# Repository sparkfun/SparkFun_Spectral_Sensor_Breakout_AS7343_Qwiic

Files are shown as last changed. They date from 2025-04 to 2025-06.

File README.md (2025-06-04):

SparkFun Spectral Sensor - AS7343 (Qwiic)
=========================================
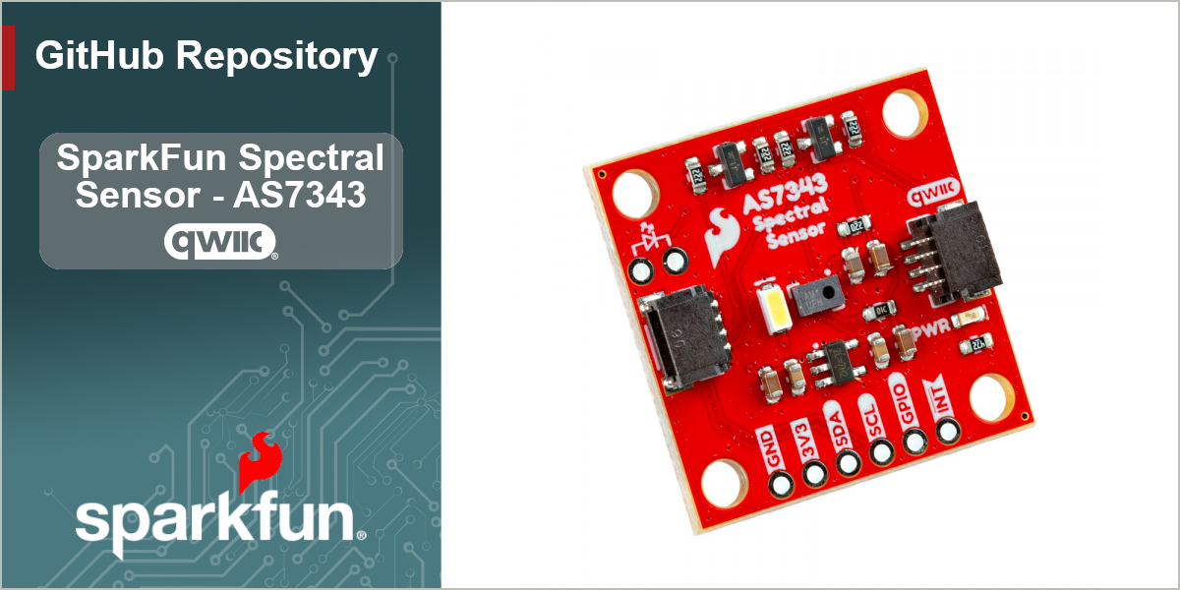
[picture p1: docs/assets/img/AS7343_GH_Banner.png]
Banner image for Spectral Sensor - AS7343 (https://www.sparkfun.com/sparkfun-spectral-sensor-as7343-qwiic.html)
 

The SparkFun Spectral Sensor Breakout - AS7343 (Qwiic) offers a highly accurate but compact spectral analysis tool for both the visible spectrum and near-infrared. The AS7343 senses light between ~380mn to 1000mn over 14 channels with 11 color bands across the visible spectrum, one near-infrared channel, one clear channel (full sensing spectrum) along with flicker detection. The AS7343 also has an interrupt pin to trigger events based on specific measurements from the sensor as well as a programmable GPIO pin to help synchronize measurements with external devices. This breakout comes standard with a bright white LED for taking measurements but also includes connection points for users who wish to use their own LED if needed.

Repository Contents
-------------------

* **/Documentation** - Data sheets, additional product information
* **/Hardware** - Eagle design files (.brd, .sch)
* **/Production** - Production panel files (.brd)
* **/docs** -  Documentation files for the Spectral UV Sensor
* **/overrides** -  Overrides for GitHub pages content

Documentation
--------------
* **[Arduino Library](https://github.com/sparkfun/SparkFun_AS7343_Arduino_Library/tree/main)** - Arduino library for the Spectral Sensor - AS7343 (Qwiic).
* **[Python Package](https://github.com/sparkfun/qwiic_as7343_py)** - Python package for the Spectral Sensor - AS7343 (Qwiic)
* **[Hookup Guide](https://docs.sparkfun.com/SparkFun_Spectral_Sensor_Breakout_AS7343_Qwiic)** - Basic hookup guide for the Spectral Sensor - AS7343 (Qwiic).

Product Versions
----------------
* [SEN-23220](https://www.sparkfun.com/sparkfun-spectral-sensor-as7343-qwiic.html) - Spectral Sensor - AS7343 (Qwiic)

License Information
-------------------

This product is _**open source**_! 

Please review the LICENSE.md file for license information. 

If you have any questions or concerns on licensing, please contact technical support on our [SparkFun forums](https://forum.sparkfun.com/viewforum.php?f=152).

Distributed as-is; no warranty is given.

- Your friends at SparkFun.

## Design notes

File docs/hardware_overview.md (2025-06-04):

Let's take a closer look at the AS7343 and other hardware on the SparkFun Spectral Sensor Breakout - AS7343. The image below highlights the major components on this Qwiic breakout board:

<figure markdown>
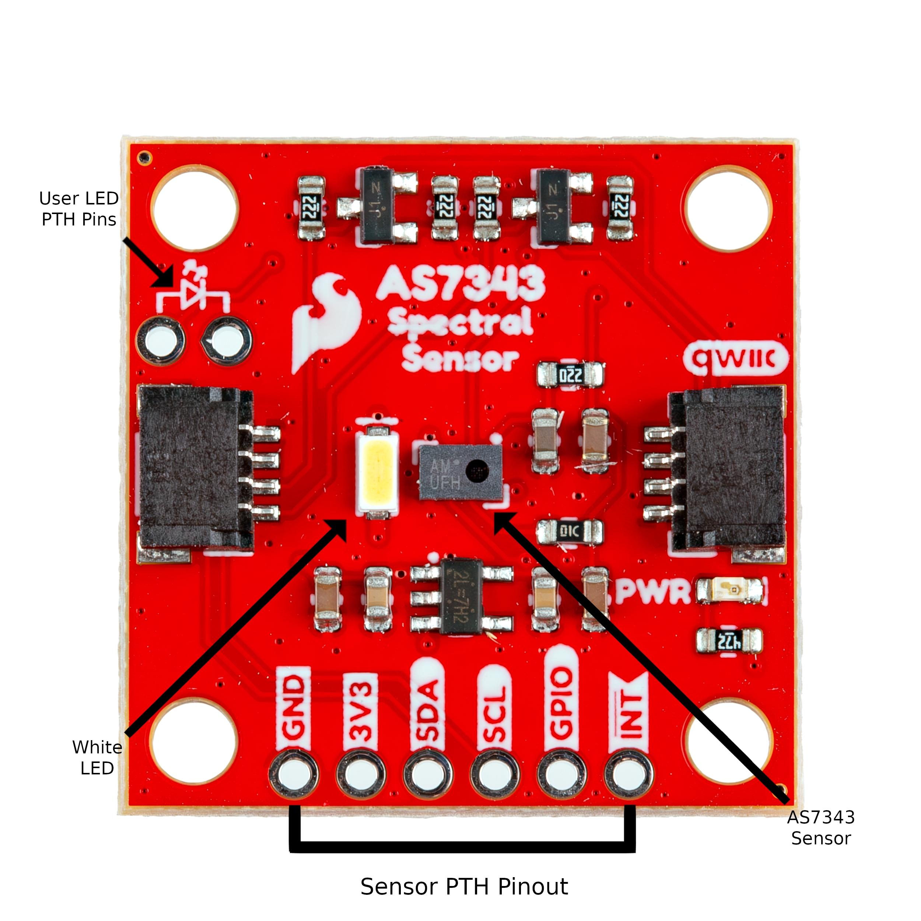
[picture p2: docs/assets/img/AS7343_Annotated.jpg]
Annotated photo of AS7343 Breakout

</figure>

## AS7343 Spectral Sensor

The AS7343 from AMS<sup>&trade;</sup> measures irradiated, reflected and transmitted light in both the visible spectrum and near-infrared (NIR). The sensor features 14 channels in a 5x5 photodiode array, enabling the detection of 11 specific color bands across the visible spectrum. Additionally, dedicated photodiodes on the outer edges of this array are designed for near-infrared (845-865 nm) and flicker detection. It has exceptional sensitivity for measuring reflected, emitted and transmitted light even in low-light environments and also behind tinted glass. 

## Power

Power for the board can be supplied either over one of the Qwiic connectors or through the <b>3.3V</b> pin. The AS7343 accepts a supply voltage between <b>1.7V</b> and <b>2V</b> so the breakout includes an on board voltage regulator to drop the <b>3.3V</b> supplied over Qwiic or <b>3.3V</b> pin to <b>1.8V</b>. This regulator has a max input voltage of <b>5.5V</b>.

## Qwiic & Pinout

The AS7343 communicates over I<sup>2</sup>C and has an active low/high interrupt pin as well as a GPIO pin. The breakout routes the SDA/SCL lines from the AS7343 to a pair of Qwiic connectors as well as the 0.1"-spaced PTH header on the side of the board. The AS7343's interrupt and GPIO are also routed to this PTH.

## LEDs

The Spectral Sensor Breakout - AS7343 has two LEDs on the board labeled <b>PWR</b> and <b>WLED</b>. The red Power (PWR) LED indicates when the board is powered. The white (WLED) LED connects to the AS7343's LED current sink pin to illuminate objects/areas during sensor readings. Users can disable the on board white LED by opening the corresponding solder jumper and connect their own LED to the PTH pins labeled .

## Solder Jumpers

The board has three solder jumpers labeled <b>I2C</b>, <b>PWR</b> and <b>WLED</b>. The <b>I2C</b> jumper is a three-way jumper that pulls the SDA/SCL lines to <b>3.3V</b> through a pair of <b>2.2k&ohm;</b> resistors and is CLOSED by default. The board also includes level shifting to drop the logic down to <b>1.8V</b> . The <b>PWR</b> jumper completes the power LED circuit and is CLOSED by default. Open the solder jumper to disable the power LED. The <b>WLED</b> jumper completes the white LED circuit and is CLOSED by default.

## Board Dimensions

The SparkFun Spectral Sensor Breakout - AS7343 matches the Qwiic breakout standard and measures 1" x 1" (22.5mm x 22.5mm) and has four mounting holes that fit a [4-40 screw](https://www.sparkfun.com/screw-phillips-head-1-4-4-40-10-pack.html).

<figure markdown>
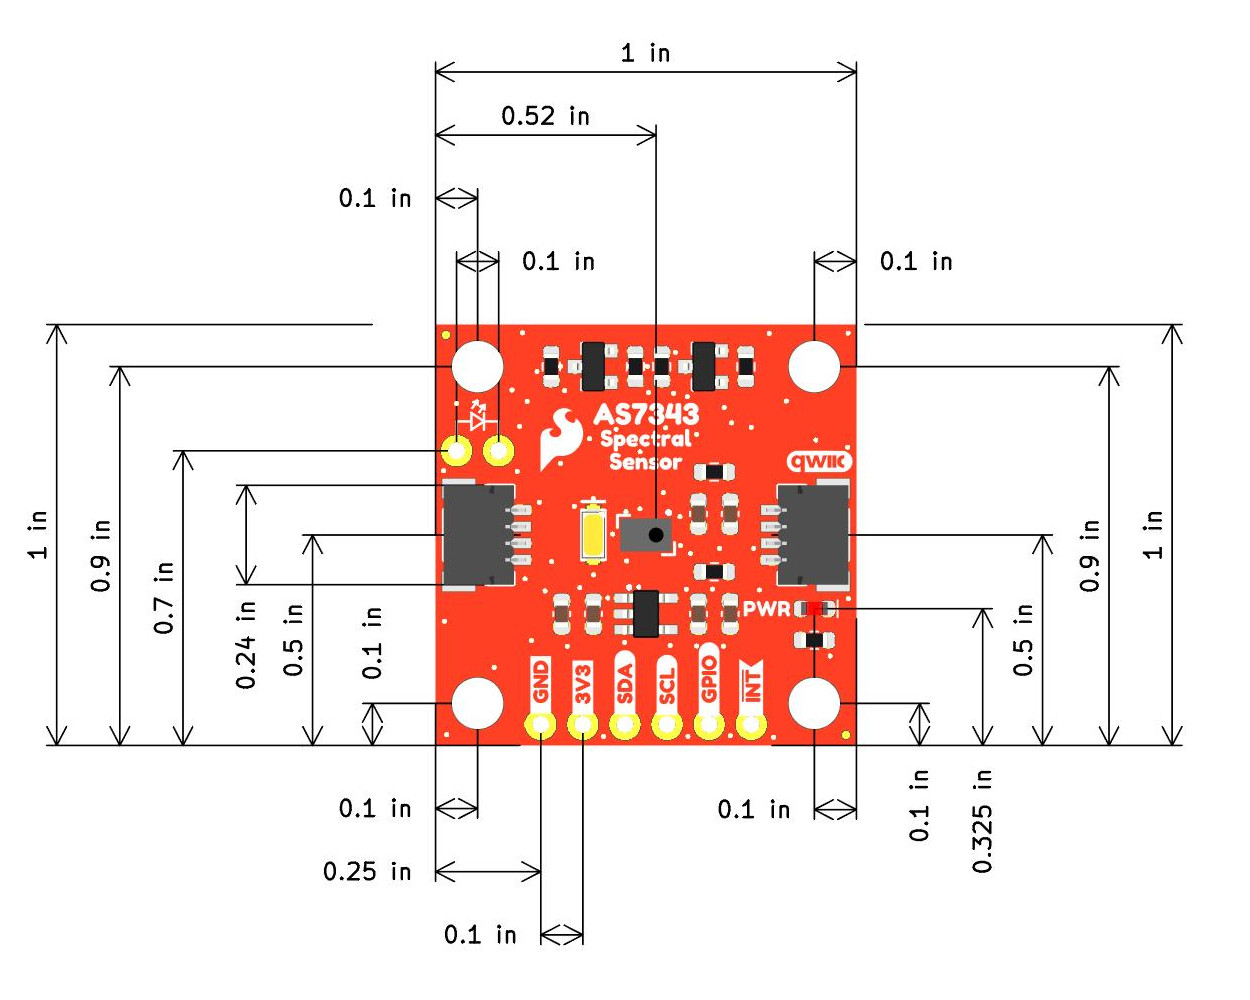
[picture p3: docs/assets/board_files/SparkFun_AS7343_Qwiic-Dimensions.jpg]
Dimensional drawing

</figure>

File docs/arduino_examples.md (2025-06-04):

Let's take a closer look at the examples included in the SparkFun AS7343 Arduino Library. This section assumes users are following the assembly instructions from the Hardware Assembly/Qwiic Start sections and are using a SparkFun RedBoard IoT - ESP32.

## Example 1 - Basic Readings

The first example sets up the AS7343 to operate with default settings and outputs data from just four channels (Red, Green, Blue and NIR). Open the example in Arduino by navigating to **File** > **Examples** > **SparkFun AS7343 Arduino Library** > **Example_01_BasicReadings**. Next, select your board (RedBoard IoT - ESP32) and Port and click the "Upload" button. After the code finishes compiling and uploading, open the [serial monitor](https://docs.arduino.cc/software/ide-v2/tutorials/ide-v2-serial-monitor/) with the baud set to **115200** and you should see readings for red, blue, green and NIR print out like the screenshot below shows:

<figure markdown>
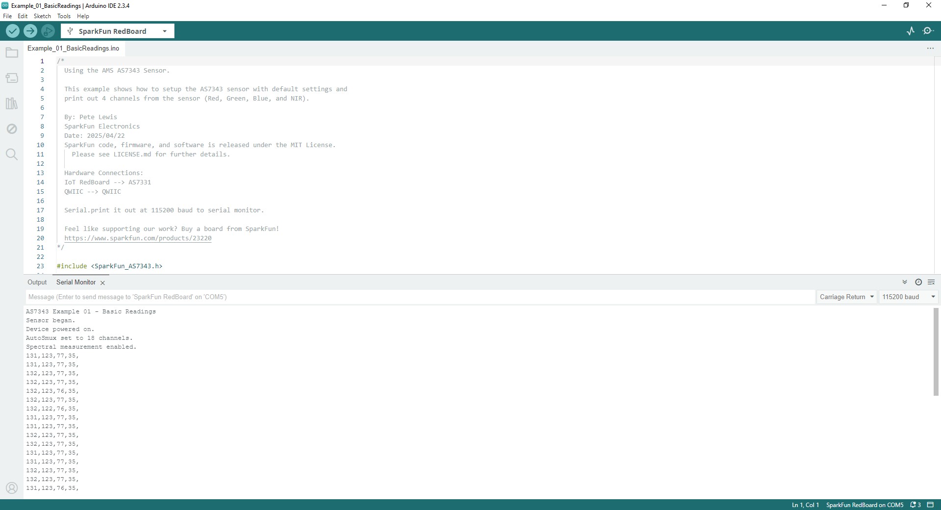
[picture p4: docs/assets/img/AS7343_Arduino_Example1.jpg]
Screenshot of example 1 serial print

</figure>

## Example 2 - All Channels

Example 2 - All Channels shows how to set up the AS7343 with default settings to print out all spectral data from the sensor. This example is nearly identical to the first outside of the serial data printed out. Instead of getting and printing data from four specific channels, this example requests data from all channels and prints it as comma separated values. Open the example in Arduino by navigating to **File** > **Examples** > **SparkFun AS7343 Arduino Library** > **Example_02_AllChannels**. 

In order to get data from all channels, the AS7343 takes measurements in three cycles with each one stepping through four individual channels combined with readings from the Clear/VIS and Flicker Detect/FD which is then stored in the sensor's data registers. The example prints out spectral data stepping through each channel from 0 to 17 in comma-separated values:

```c++
    for (int channel = 0; channel < channelsRead; channel++)
    {
        Serial.print(myData[channel]);
        Serial.print(",");
    }

    Serial.println();
```

## Example 3 - Gain

The third example shows how to set up the AS7343 with specific Spectral Engines Gain Settigns (aka AGAIN) and cycle through the gain settings using serial commands. Open the example in Arduino by navigating to **File** > **Examples** > **SparkFun AS7343 Arduino Library** > **Example_03_Gain**. If necessary, select your board and port and click the "Upload" button. Open the serial terminal with the baud set to **115200** after the code finishes uploading. 

The example accepts serial inputs of "+" and "-" to step up and down, respectively, through the available gain settings and prints out the value of the gain each time it's updated:

```c++
    if(Serial.available())
    {
        userInput = Serial.read();
        if (userInput == '+' || userInput == '-')
        {
            updateGainSetting(userInput);
        }
    }
```

The code also prints out spectral readings from all channels every 1 second so'll want to pay close attention to the serial monitor when adjusting the gain value to see the returned serial data like the screenshot below shows:

<figure markdown>
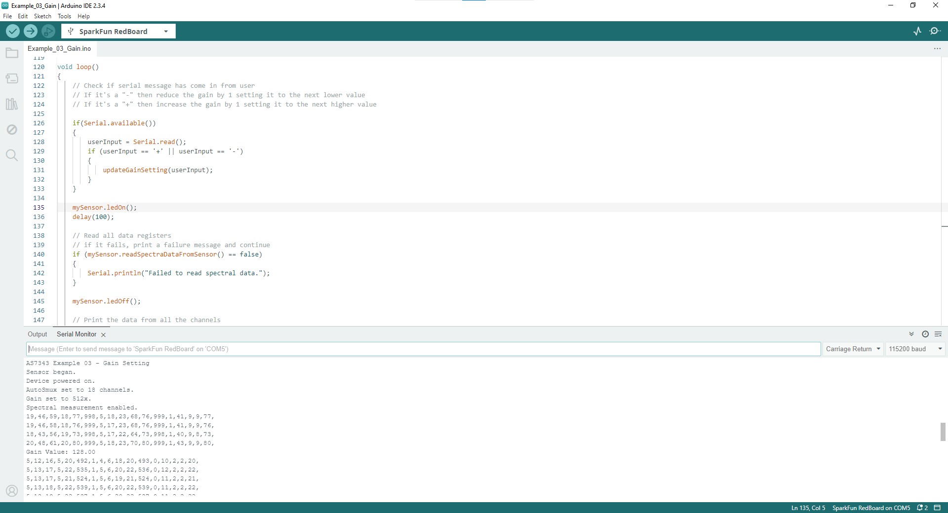
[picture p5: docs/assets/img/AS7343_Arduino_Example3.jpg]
Screenshot of Example 3 - Gain serial printout.

</figure>

## Example 4 - Interrupt

The fourth example demonstrates how to set up the AS7343's interrupt pin to fire when values from a specific channel exceed a specified limit. The example defaults to watch channel FZ (450nm aka Blue) and trigger the interrupt when it reports values over 10 counts. The example defaults to use `D4` for the interrupt pin so depending on whether or not your board supports external interrupts adjust this line if needed:

```c++
#define INT_HW_READ_PIN 4 // Pin to read the interrupt pin from the AS7343
```

Not sure which pins on your development board support the `attachInterrupt()` function in Arduino? Take a look at [this page](https://docs.arduino.cc/language-reference/en/functions/external-interrupts/attachInterrupt/) for a more thorough reference on the function along with available interrupt pins for common Arduino development boards.

## Example 5 - Flicker Detection

Example five shows how to set up and monitor flicker detection readings from the sensor. It sets up the AS7343 with default settings with flicker detection enabled. It then checks to see if flicker detection values are invalid or saturated and prints out for either case:

**Flicker Detection is Invalid**
```c++
if (fdValid == false)
    {
        Serial.print("Flicker Detection Measurement Invalid");
        Serial.println();
        delay(1000);
        return;
    }
```
**Flicker Detection Saturated**
```c++
    if (fdSaturation == true)
    {
        Serial.print("Flicker Detection Saturation Detected");
        Serial.println();
        delay(1000);
        return;
    }
```

If the flicker detection value is valid and not saturated, it reads the value and prints it in Hz over serial:

```c++
    if(fdValid == true && fdSaturation == false)
    {
        if (fdFrequency == 0) // if getFlickerDetectionFrequency() returns 0, no frequency detected
            Serial.print("No Flicker Detected");
        else
        {
            Serial.print("Flicker Detected at frequency: ");
            Serial.print(fdFrequency);
            Serial.print("Hz");
        }
        Serial.println();
    }

    delay(1000);
```

## Example 6 - Sleep

Example six shows how to put the AS734 in and out of "sleep" to take intermittent measurements. Note, the AS7343 [datasheet](./assets/component_documentation/AS7343_DS001046_6-00.pdf) refers to each mode of operation as Sleep, Idle and Active. There is no direct control of a power mode but we can turn off the Measurement and the Power ON bits in the Enable register to put the AS7343 into a low power state that draws ~350uA. This example creates helper functions to wake the sensor, take a reading and then put the sensor back to sleep once every five seconds in the main loop:

```c++
void loop()
{
    takeReading(); // Wake up and take a reading from the sensor

    sleepSensor(); // Disables measurement (IDLE) and powers off (SLEEP)

    delay(5000); // Wait 5 seconds to allow reading sleep current if needed.
}
```

## Example 7 - Web Terminal Bar Graph

The seventh example takes data from all of the AS7343's channels (visible spectrum, NIR and clear) and formats it in a way to work with the SparkFun [Web Serial Plotter](https://docs.sparkfun.com/SparkFun_WebSerialPlotter/) tool to display the readings in a colorful bar graph. After uploading the code, open the [SparkFun Web Serial Plotter](https://docs.sparkfun.com/SparkFun_WebSerialPlotter/) site, select the COM port with the baud set to <b>115200</b> and click connect. You should start to see serial data print out in the top window along with a bar graph matching the channel data in the bottom window:

<figure markdown>
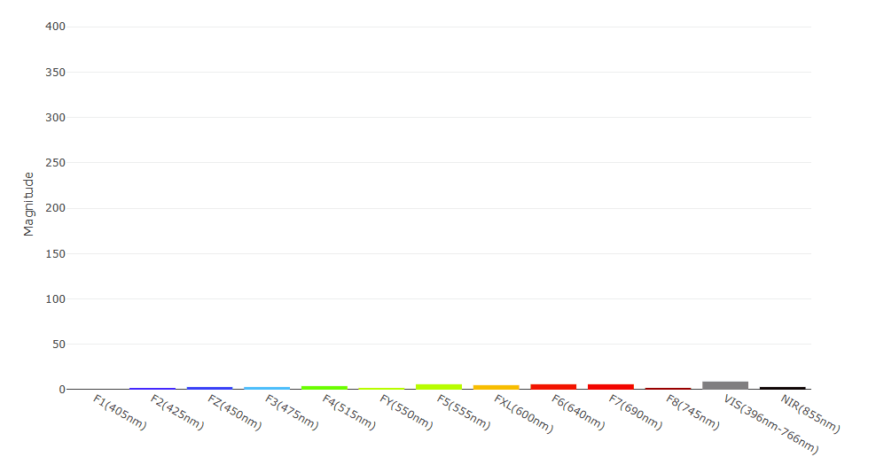
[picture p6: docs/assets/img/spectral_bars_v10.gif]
Gif of bar graph demo

</figure>

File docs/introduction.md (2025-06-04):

<figure markdown>
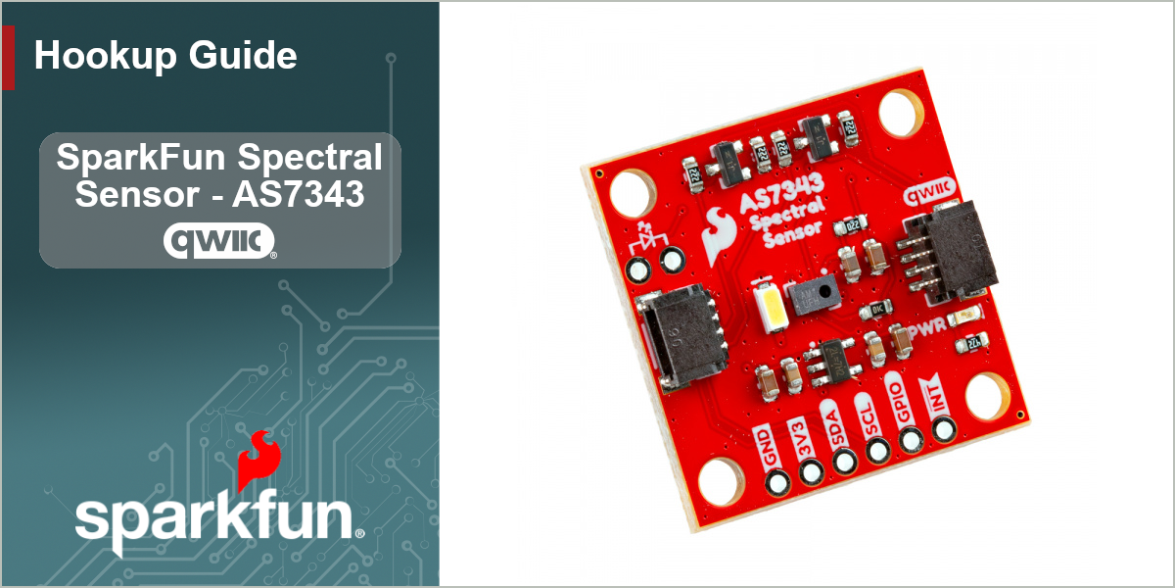
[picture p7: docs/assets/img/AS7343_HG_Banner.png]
Spectral Sensor Breakout Banner Image

</figure>

The SparkFun Spectral Sensor Breakout - AS7343 (Qwiic) offers a highly accurate but compact spectral analysis tool for both the visible spectrum and near-infrared. The AS7343 senses light between ~380mn to 1000mn over 14 channels with 11 color bands across the visible spectrum, one near-infrared channel, one clear channel (full sensing spectrum) along with flicker detection. The AS7343 also has an interrupt pin to trigger events based on specific measurements from the sensor as well as a programmable GPIO pin to help synchronize measurements with external devices. This breakout comes standard with a bright white LED for taking measurements but also includes connection points for users who wish to use their own LED if needed.

This guide covers how to get spectral data from the AS7343 using both Arduino and MicroPython when connecting the Spectral Sensor Breakout to a compatible development board over Qwiic. In order to follow along with this guide you'll need the Spectral Sensor Breakout - AS7343 along with the following materials:

* [SparkFun IoT RedBoard - ESP32 MicroPython Development Board](https://www.sparkfun.com/sparkfun-iot-redboard-esp32-micropython-development-board.html) (or other Arduino/MicroPython development board)
* [Qwiic Cable](https://www.sparkfun.com/qwiic-cable-100mm.html)
* [USB-C Cable](https://www.sparkfun.com/usb-a-to-usb-c-cable-1m-usb-2-0-flexible-silicone.html) 

If you plan to use the AS7343's Interrupt/GPIO pins or prefer a soldered connection, you may need one or more of these materials along with a [soldering iron](https://www.sparkfun.com/tools/soldering/soldering-irons-and-tips.html) and [solder](https://www.sparkfun.com/tools/soldering/solder.html):

* [Breakaway Headers Straight](https://www.sparkfun.com/break-away-headers-straight.html)
* [Jumper Wires - Connected 6" (M/M, 20 pack)](https://www.sparkfun.com/jumper-wires-connected-6-m-m-20-pack.html)
* [Breadboard](https://www.sparkfun.com/breadboard-self-adhesive-white.html)

## Topics Covered

This document contains three main sections: **Quickstart Guide**, **Hardware** and **Software**. 

The Quickstart Guide assumes a working knowledge of how to use a development board and the required software to program them for your project's needs. It covers a quick assembly and then jumps right into getting the necessary software packages installed to start getting spectral data in just a few short minutes.

The Hardware pages are split into the Hardware Overview and Hardware Assembly. The Hardware Overview provides a detailed overview of the Spectral Sensor Breakout - AS7343 along with all the major components included on the board. Refer to this page for information on things like the AS7343, LEDs, pinout and solder jumpers. The Hardware Assembly page covers how to assemble the breakout in both a Qwiic circuit as well as how to use the optional soldered features such as the external LED and the AS7343's Interrupt/GPIO pins.

The Software pages are split into sections covering the SparkFun AS7343 Arduino Library and MicroPython driver. Each software page gives instructions on how to download install the software package (Arduino library or MicroPython driver), as well as detailed looks at the examples included in the software packages.

## Resources and Support Documentation 

You'll find the board design files (KiCad files & schematic), relevant documentation (datasheets, white papers, etc.) and other helpful links in the **Resources**. Lastly, the **Support** section includes a Troubleshooting page that includes any helpful tips specific to this board as well as information on how to receive technical support from SparkFun.

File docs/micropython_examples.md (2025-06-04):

Let's take a quick look at each example included in the SparkFun AS7343 Python package. Note, the naming of these examples matches the examples in the Arduino library and skips from 3 to 5 as this package does not have an interrupt example (Example 4 in the Arduino library).

## Example 1 - Basic Readings

This simple example demonstrates how to set up the AS7343 with default settings and though it does set the AS7343 to report data from all 18 channels it only prints data for four channels (Red, Green, Blue and NIR) using this command:

```py
	print(myAS7343.get_blue(), end=',')
		print(myAS7343.get_red(), end=',')
		print(myAS7343.get_green(), end=',')
		print(myAS7343.get_nir(), end=',\n')
```

## Example 2 - All Channels

Example 2 demonstrates how to set up the AS7343 to output data from all channels on the sensor in comma-separated values by steping through all channels:

```py
	for i in range(0, myAS7343.kNumChannels):
			print(myAS7343.get_data(i), end=',')
		print()
```

## Example 3 - Gain

The third example shows how to set the gain for the AS7343. It defaults to set the gain as `512x` but you can adjust it in this line:

```py
if not myAS7343.set_a_gain(myAS7343.kAgain64):
```

Refer to the main .py file [here](https://github.com/sparkfun/qwiic_as7343_py/blob/master/qwiic_as7343.py#L102) for all allowed values for gain settings.

## Example 5 - Flicker Detection

The Flicker Detection example demonstrates how to use the AS7343's flicker detection feature. It initializes the sensor with default settings and then prints out flicker detection vlues in Hz to the serial monitor:

```py
if fdFrequency == 0:
			print("No flicker detected")
		else:
			print("Flicker detected at frequency: {} Hz".format(fdFrequency))

		time.sleep(1)
```

## Example 6 - Sleep

The sixth example shows how to create a `def` to cycle the AS7343 in and out of "sleep" between measurement reports to help conserve power:

```py
def sleep_device(device):
	# Disable spectral measurements
	if not device.spectral_measurement_disable():
		print("Failed to disable spectral measurements", file=sys.stderr)
		return
	print("Spectral measurements disabled")

	# Power off the device
	if not device.power_off():
		print("Failed to power off the device", file=sys.stderr)
		return
	print("Device powered off")
```

The main example then initializes the sensor with default settings, takes readings, puts it to sleep for 5 seconds and then loops:

```py
	while True:
		# Take a reading
		take_reading(myAS7343)

		# Put the device to sleep
		sleep_device(myAS7343)

		# Wait 5 seconds before taking another reading
		time.sleep(5.0)
```

Though there is no direct control of a power mode, the example turns off the measurement and Power ON bits in the Enable register to put the sensor into a low power state so it draws ~350&micro;A.

## Example 7 - Web Bar Graph

Example 7 shows how to use the Spectral Sensor with the SparkFun [Web Serial Plotter](https://docs.sparkfun.com/SparkFun_WebSerialPlotter/) to display spectral data from all channels in a neat and colorful bar graph. You'll need to run this on a microcontroller like the [IoT RedBoard - ESP32 MicroPython](https://www.sparkfun.com/sparkfun-iot-redboard-esp32-micropython-development-board.html) as the Web Serial Plotter connects over a serial COM port. The code initializes the AS7343 with default settings and then prints out the comma-separated values in a format compatible with the web serial plotter:

```py
print(f"{myAS7343.get_data(myAS7343.kChPurpleF1405nm)},"
          f"{myAS7343.get_data(myAS7343.kChDarkBlueF2425nm)},"
          f"{myAS7343.get_data(myAS7343.kChBlueFz450nm)},"
		  f"{myAS7343.get_data(myAS7343.kChLightBlueF3475nm)},"
		  f"{myAS7343.get_data(myAS7343.kChBlueF4515nm)},"
		  f"{myAS7343.get_data(myAS7343.kChGreenF5550nm)},"
		  f"{myAS7343.get_data(myAS7343.kChGreenFy555nm)},"
		  f"{myAS7343.get_data(myAS7343.kChOrangeFxl600nm)},"
		  f"{myAS7343.get_data(myAS7343.kChBrownF6640nm)},"
		  f"{myAS7343.get_data(myAS7343.kChRedF7690nm)},"
		  f"{myAS7343.get_data(myAS7343.kChDarkRedF8745nm)},"
		  f"{myAS7343.get_data(myAS7343.kChVis1)},"
		  f"{myAS7343.get_data(myAS7343.kChNir855nm)}\n", end='')
```

After running the example, open the [Web Serial Plotter](https://docs.sparkfun.com/SparkFun_WebSerialPlotter/) and select the COM port and click "Connect" and you should see serial data print out in the top window and a nice colorful bar graph in the bottom window like the gif below shows:

<figure markdown>
Gif of serial plotter bar graph spectral data
</figure>

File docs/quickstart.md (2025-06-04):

In this Quick Start Guide we'll connect the SparkFun Spectral Sensor Breaout - AS7343 (Qwiic) to an IoT RedBoard - ESP32 to output measurements of visible and near-infrared light and display them in a colorful web terminal bar graph.

If you're not familiar with using sensor breakouts, development boards or the development environments covered in this guide, refer to the [Hardware](./hardware_overview.md) & [Arduino Setup](./arduino_setup.md) sections of this Hookup Guide for a detailed overview of the board along with instructions on setting up and using the SparkFun AS7343 Arduino Library. For those who prefer to run this example in MicroPython, read on to the [AS7343 Python Setup](./micropython_setup.md) and [Python Examples](./micropython_examples.md) sections of this guide.

## Basic Assembly

As this is a Qwiic breakout, assembling the circuit only requires connecting the sensor breakout to a Qwiic-compatible development board like the IoT RedBoard - ESP32. Connect the Spectral Sensor Breakout to the IoT RedBoard with a Qwiic cable and then connect the IoT RedBoard to your computer with a USB-C cable like the photo below demonstrates:

<figure markdown>
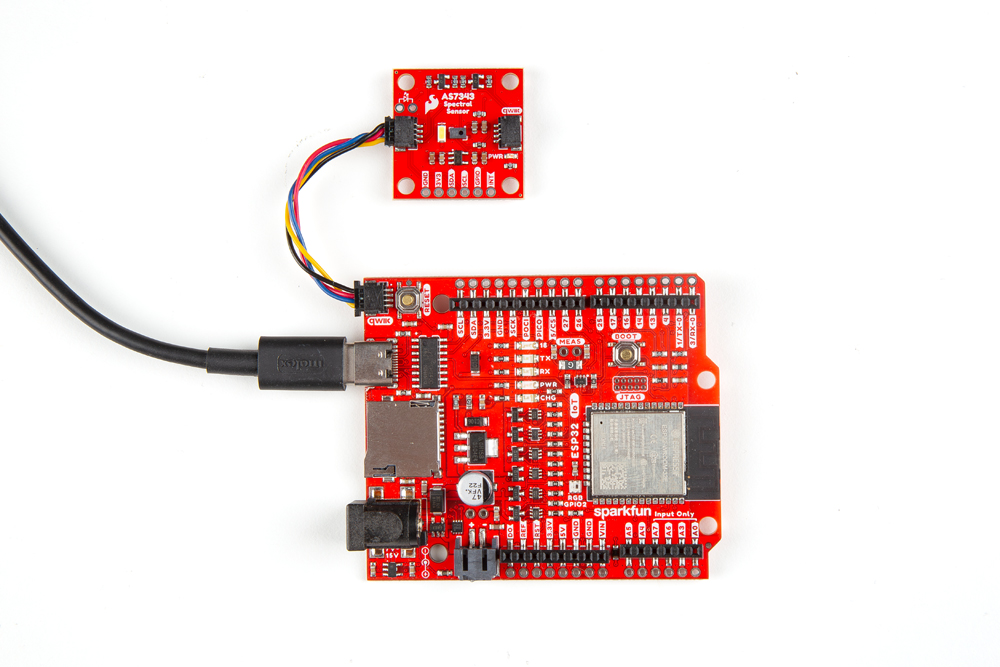
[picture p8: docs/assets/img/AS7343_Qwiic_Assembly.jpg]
Photo of Qwiic assembly with RedBoard IoT - ESP32

</figure>

## Arduino Web Terminal Bar Graph Example

The Arduino Web Terminal Bar Graph example sets up the AS7343 to output from all channels and format the data to work with the [SparkFun Web Serial Plotter](https://docs.sparkfun.com/SparkFun_WebSerialPlotter/) tool and display it in a bar graph. The Web Terminal Bar Graph site only works in a Chromium-based browser (sorry, no Firefox) and just requires a serial connection over USB to your microcontroller.

* Open the [Arduino IDE](https://docs.arduino.cc/software/ide-v2/tutorials/getting-started-ide-v2/)
* Open the [Library Manager](https://docs.arduino.cc/software/ide-v1/tutorials/installing-libraries/) tool and search for "SparkFun Toolkit" and "SparkFun AS7343" and install the latest versions of both libraries.
* If necessary, open the [Boards Manager](https://docs.arduino.cc/software/ide-v2/tutorials/ide-v2-board-manager/) and search for "ESP32" to install the IoT RedBoard - ESP32 board definition.
* Open "Example 7 - Web Terminal Bar Graphs" from the SparkFun AS7343 Arduino Library and select your board (IoT RedBoard - ESP32) and Port.
* Click the "Upload" button and wait for the code to finish compiling and uploading.
* Open [this link](https://docs.sparkfun.com/SparkFun_WebSerialPlotter/) in a browser and select the COM port of the IoT RedBoard.
* Try moving the Spectral Sensor around and pointing it at different objects/colors and watch the Bar Graph in the bottom half of the window update every 1s like the gif below.

<figure markdown>
Screencapture of bar graph in motion
</figure>

**Code to Note**

The code begins by setting the AS7343 to operate with default settings and prints out whether or not it fails or begins:

```c++
    if (mySensor.begin() == false)
    {
        Serial.println("Sensor failed to begin. Please check your wiring!");
        Serial.println("Halting...");
        while (1)
            ;
    }

    Serial.println("Sensor began.")
```

After initializing the sensor and powering it on, the code then sets the AS7343's AutoSmux to output all 18 channels and prints out the result:

```c++
    if (mySensor.setAutoSmux(AUTOSMUX_18_CHANNELS) == false)
    {
        Serial.println("Failed to set AutoSmux.");
        Serial.println("Halting...");
        while (1)
            ;
    }
    Serial.println("AutoSmux set to 18 channels.");
```

The main loop turns the white LED on to illuminate the sensing area and then takes a reading from all channels once per second:

```c++
    mySensor.ledOn();
    delay(100);

    // Read all data registers
    // if it fails, print a failure message and continue
    if (mySensor.readSpectraDataFromSensor() == false)
    {
        Serial.println("Failed to read spectral data.");
    }
```

Finally, in order to format the data for the web serial terminal, the code fills the buffer with channel data in a specific order and prints the buffer for the web terminal to output the bar graph data correctly:

```c++
    sprintf(buffer, "%d,%d,%d,%d,%d,%d,%d,%d,%d,%d,%d,%d,%d\n",
           mySensor.getChannelData(CH_PURPLE_F1_405NM),
           mySensor.getChannelData(CH_DARK_BLUE_F2_425NM),
           mySensor.getChannelData(CH_BLUE_FZ_450NM),
           mySensor.getChannelData(CH_LIGHT_BLUE_F3_475NM),
           mySensor.getChannelData(CH_BLUE_F4_515NM),
           mySensor.getChannelData(CH_GREEN_F5_550NM),
           mySensor.getChannelData(CH_GREEN_FY_555NM),
           mySensor.getChannelData(CH_ORANGE_FXL_600NM),
           mySensor.getChannelData(CH_BROWN_F6_640NM),
           mySensor.getChannelData(CH_RED_F7_690NM),
           mySensor.getChannelData(CH_DARK_RED_F8_745NM),
           mySensor.getChannelData(CH_VIS_1),
           mySensor.getChannelData(CH_NIR_855NM));

    Serial.print(buffer);
```

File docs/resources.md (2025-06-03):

Refer to the resources below for more information on the SparkFun Spectral Sensor Breakout - AS7343 (Qwiic)

* [Schematic](./assets/board_files/SparkFun_AS7343_Qwiic.pdf)
* [KiCad Files](./assets/board_files/SparkFun_AS7343_Qwiic.zip)
* [Board Dimensions](./assets/board_files/SparkFun_AS7343_Qwiic-Dimensions.jpg)
* [Datasheet](./assets/component_documentation/AS7343_DS001046_6-00.pdf) (AS7343)
* [SparkFun AS7343 Arduino Library](https://github.com/sparkfun/SparkFun_AS7343_Arduino_Library)
* [SparkFun AS7343 Python Package](https://github.com/sparkfun/qwiic_as7343_py)
* [GitHub Repository](https://github.com/sparkfun/SparkFun_Spectral_Sensor_Breakout_AS7343_Qwiic)

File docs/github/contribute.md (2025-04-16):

# Contribute: Make an Augmentation!
Spot an improvement opportunity? Feel free to contribute to our open-source design and documentation. 

## :material-file-document-multiple:&nbsp;Improve our Documentation
All of this documentation can be modified by you! Please help us make it better.

* These pages are contained in the [`docs` folder](https://github.com/sparkfun/SparkFun_Spectral_Sensor_Breakout_AS7343_Qwiic/tree/main/docs) of the [SparkFun Spectral Sensor Breakout - AS7343 (Qwiic) repository](https://github.com/sparkfun/SparkFun_Spectral_Sensor_Breakout_AS7343_Qwiic).

<!-- ### :material-source-pull:&nbsp;Submit a Correction -->
### Submit a Correction

1. With a GitHub account, [fork this repository](https://github.com/sparkfun/SparkFun_Spectral_Sensor_Breakout_AS7343_Qwiic/fork).
2. Add your corrections or improvements to the markdown file.
3. File a pull request with your changes, and enjoy making the ~~words~~ ~~worlds~~ world a better place.
	* Once received, the documentation specialist will automatically be notified.
	* We will review your suggested improvements to make sure they are correct and fit within our documentation standards.

## :material-cog:&nbsp;Improve our Hardware Design
All of our designs are open-source! Please help us make it better.

* Our board design files are contained in the [`Hardware` folder](https://github.com/sparkfun/SparkFun_Spectral_Sensor_Breakout_AS7343_Qwiic/tree/main/Hardware) of the [Spectral_Sensor_Breakout_AS7343_Qwiic repository](https://github.com/sparkfun/SparkFun_Spectral_Sensor_Breakout_AS7343_Qwiic).

<!-- ### :material-source-pull:&nbsp;Submit a Design Enhancement -->
### Submit a Design Enhancement

1. With a GitHub account, [fork this repository](https://github.com/sparkfun/SparkFun_Spectral_Sensor_Breakout_AS7343_Qwiic/fork).
2. Add your design augmentation(s)
3. File a pull request with your changes, and enjoy making the ~~words~~ ~~worlds~~ world a better place.
	1. Once received, the engineer in charge of the original design will automatically be notified.
	2. We will review your suggested improvement(s) to verify that they are within our board design standards and meet our product design requirements.
	3. If approved, we will flag these changes for our next board revision. Congrats! 🍻

		!!! info
			Even if your suggestion is accepted, these changes may not be immediately available for purchase. We may have to cycle through our current product inventory first.

## Contributors&nbsp;:clap:
Let's provide some recognition to the contributors for this project!

GitHub Contributors Image
<br>


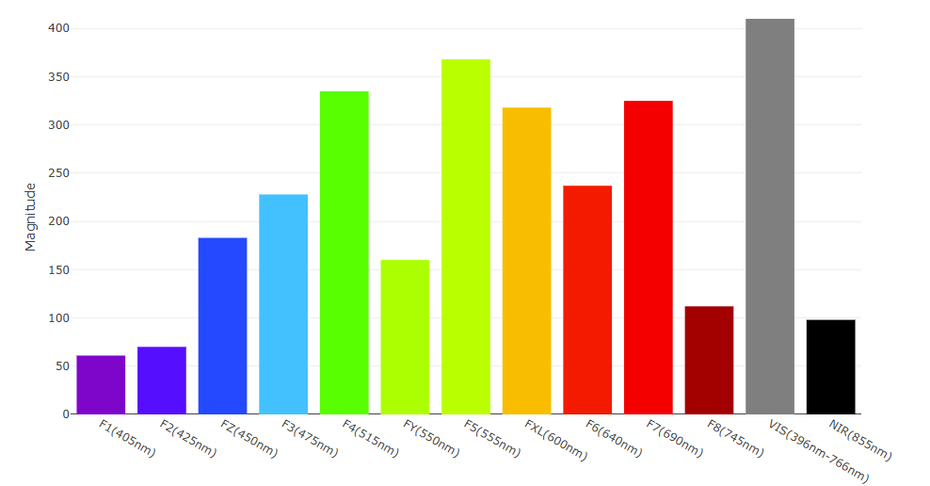
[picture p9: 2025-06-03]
docs/assets/img/spectral_sensor_bars_image.png

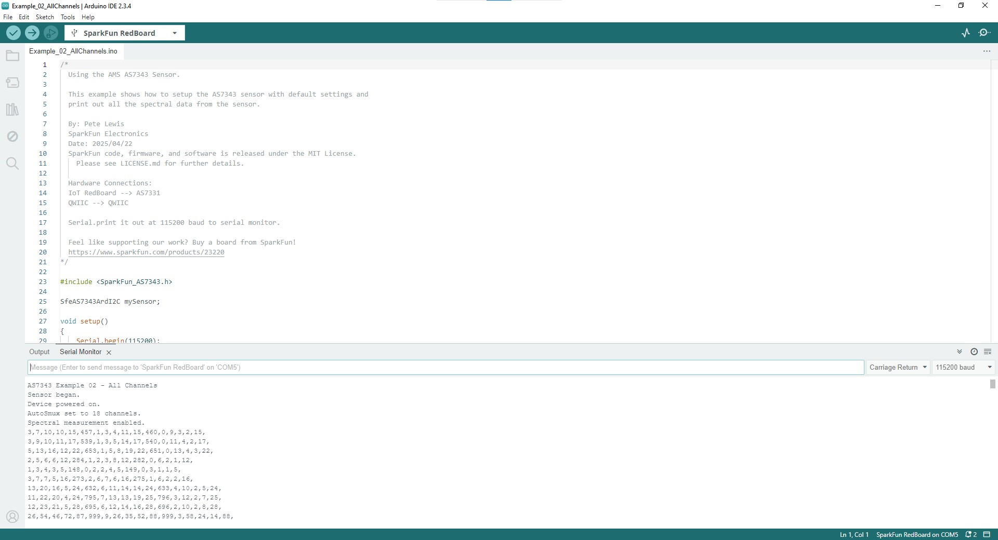
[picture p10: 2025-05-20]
docs/assets/img/AS7343_Arduino_Example2.jpg

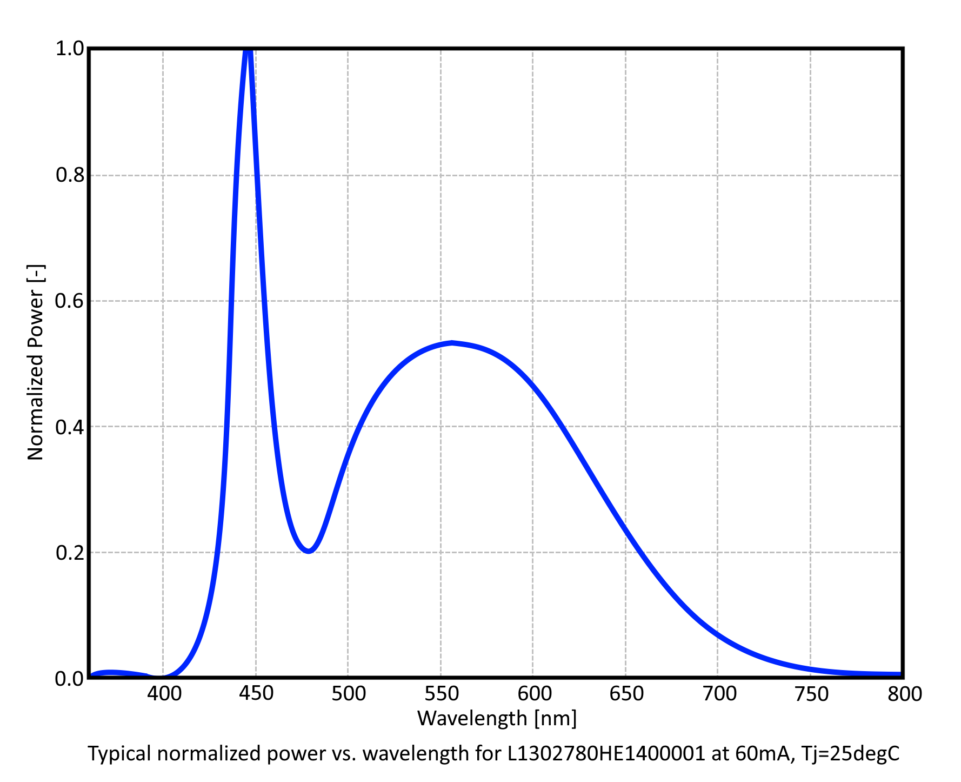
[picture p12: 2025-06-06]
Documents/LUXEON_LED_power_graph.png

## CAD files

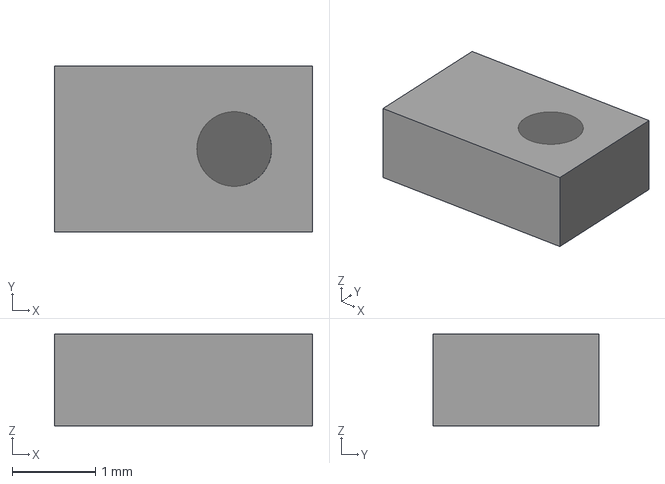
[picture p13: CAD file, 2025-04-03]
Hardware/3D_Models/AS7343_OLGA8.step
3.10 x 2.00 x 1.10 mm

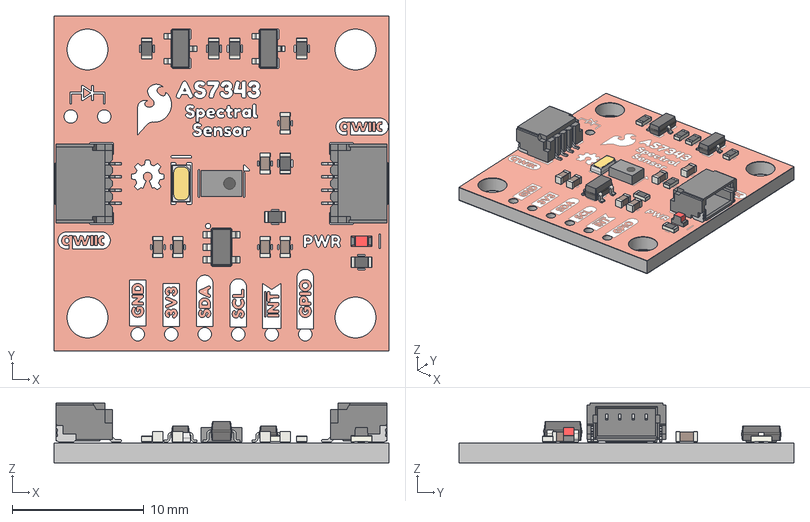
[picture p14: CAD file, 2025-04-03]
Hardware/SparkFun_AS7343_Qwiic.step
25.4 x 25.4 x 4.63 mm
C_0603_1608Metric x 6
R_0603_1608Metric x 7
LUXEON_3014
LED_0603_1608Metric_Red
SOT-23-5
Qwiic-Horizontal x 2
AS7343_OLGA8
SOT-23 x 2
SparkFun_AS7343_Qwiic_silkscreen
SparkFun_AS7343_Qwiic_soldermask
SparkFun_AS7343_Qwiic_PCB

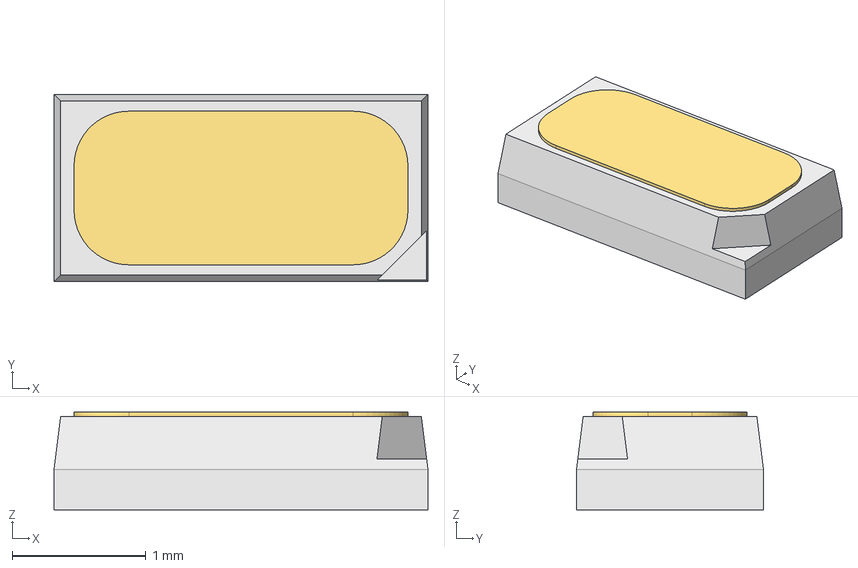
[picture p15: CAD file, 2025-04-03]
Hardware/3D_Models/LUXEON_3014.step
2.80 x 1.40 x 0.73 mm

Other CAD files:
Hardware/3D_Models/AS7343_OLGA8.FCStd
Hardware/3D_Models/LUXEON_3014.FCStd

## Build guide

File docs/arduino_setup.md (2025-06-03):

!!! arduino
    This example assumes you are using the latest version of the Arduino IDE on your desktop. If this is your first time using Arduino IDE, library, or board add-on, please readh through the following tutorials:

    - [Installing the Arduino IDE](https://learn.sparkfun.com/tutorials/installing-arduino-ide)
    - [Installing an Arduino Library](https://learn.sparkfun.com/tutorials/installing-an-arduino-library)
    - [Installing Board Definitions in the Arduino IDE](https://learn.sparkfun.com/tutorials/installing-board-definitions-in-the-arduino-ide)

The SparkFun AS7343 Arduino Library helps users get started with the AS7343 with seven examples that go through how to use different features of the AS7343. The library is built around the [SparkFun Arduino Toolkit](https://github.com/sparkfun/SparkFun_Toolkit) and requires installation of both libraries to work. Install the libraries using the [Arduino library manager](https://docs.arduino.cc/software/ide-v1/tutorials/installing-libraries/) by opening the tool and searching for "SparkFun Toolkit" and "SparkFun AS7343" and installing the latest releases of both libraries. Users who prefer to manually install the libraries can download ZIP files of them here: [SparkFun Toolkit (ZIP)](https://github.com/sparkfun/SparkFun_Toolkit/archive/refs/heads/main.zip) and [SparkFun AS7343 Arduino Library (ZIP)](https://github.com/sparkfun/SparkFun_AS7343_Arduino_Library/archive/refs/heads/main.zip).

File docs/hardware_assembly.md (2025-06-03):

Now that we're familiar with the hardware on this Qwiic breakout, let's build it into a Qwiic circuit to start getting spectral data from the AS7343.

## Qwiic Assembly

The Qwiic system allows solderless connections for power and I<sup>2</sup>C so all you need to get up and running is a Qwiic cable and Qwiic compatible development board (or a Qwiic adapter cable). Assemble your Qwiic circuit by connecting the Spectral Sensor Breakout - AS7343 to your development board with the Qwiic cable and then connecting the development board to your computer over USB like the photo below shows:

<figure markdown>
Photo of Qwiic assembly with RedBoard IoT - ESP32
</figure>

## Using an External LED

If you'd like to install your own LED on the breakout board you'll need to disable the on-board LED and solder in your chosen replacement. Start by opening the "WLED" solder jumper and then solder the new LED to the pads with the diode symbol (labeled <b>USER</b> on the reverse of the board). Make sure to match the LED's polarity to the diode symbol like the photo below shows:

<figure markdown>
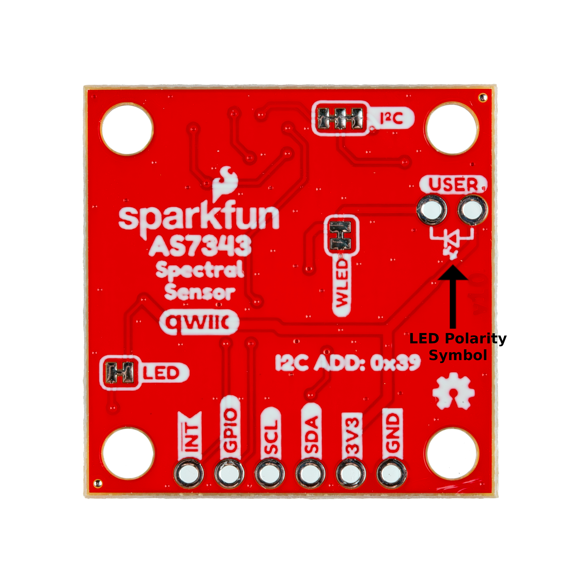
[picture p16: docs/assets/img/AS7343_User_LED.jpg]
Photo highlighting LED polarity symbol

</figure>

## Soldered Assembly

Users who prefer a soldered connection or need to use the AS7343's Interrupt and/or GPIO pins in a permanent assembly should solder to the 0.1"-spaced PTH header on the board. We opted to solder [straight headers](https://www.sparkfun.com/break-away-headers-straight.html) to this PTH header for prototyping the circuits for the Interrupt and GPIO code examples further along in this guide.

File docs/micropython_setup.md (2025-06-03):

The SparkFun AS7343 Python Package is based off the Arduino library for the sensor to get users started with example code for the AS7343. It works for Python, MicroPython and CircuitPython so you can choose which "flavor" of Python to use. This section goes over how to install the package in each supported Python environment along with the necessary tools for installation and running examples.

## Python Installation

For users on a Linux-based system (Raspberry Pi, etc.), install this package in Python with PyPi using the `pip3` command with the following steps:

* Set up a virtual environment from a specific directory using `venv`: `python3 -m venv path/to/venv (You can use any path here just remember to use the same one for each step).
* Install the Qwiic package: `path/to/venv/bin/pip3 install sparkfun-qwiic-as7343

That's it. Now you can run any example (or your own custom scripts) by running it with a command like: `path/to/venv/bin/python3 qwiic_as7343_ex1_basic_readings.py`

## MicroPython Installation

If you prefer to use MicroPython to run the examples on a microcontroller running MicroPython, follow these steps to install the package on your computer:

* Install [mpremote](https://docs.micropython.org/en/latest/reference/mpremote.html) on your computer.
* Connect the IoT RedBoard - ESP32 (or other MicroPython device) to your computer and install the package directly using mpremote mip: `mpremote mip install github:sparkfun/qwiic_as7343_py`
* Install the examples to the IoT RedBoard with the following mip command: `mpremote mip install github:sparkfun/qwiic_as7343_py@examples`

## CircuitPython Installation

Lastly, users who prefer CircuitPython can install the package with the following steps:

* Install [CircUp](https://docs.circuitpython.org/projects/circup/en/latest/#installation) on your computer.
* Make sure you have the latest version of the SparkFun Qwiic CircuitPython module installed with this command: `circup bundle-add sparkfun/Qwiic_py`
* Connect your CircuitPython device to your computer and install the package to the divice with circup: `circup install --py qwiic_as7343`

If you want to install specific examples from the repository, use the following command:

`
circup example qwiic_as7343\qwiic_as7343_ex1_basic_readings
circup example qwiic_as7343\qwiic_as7343_ex2_all_channels
circup example qwiic_as7343\qwiic_as7343_ex3_gain
circup example qwiic_as7343\qwiic_as7343_ex5_flicker_detection
circup example qwiic_as7343\qwiic_as7343_ex6_sleep
`

Note, the syntax used here are for Windows commands; Linux and Mac have different path separators. Refer to the [CircUp "example command documentation](https://learn.adafruit.com/keep-your-circuitpython-libraries-on-devices-up-to-date-with-circup/example-command) for more information.

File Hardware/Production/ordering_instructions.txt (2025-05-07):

Ordering Instructions:
Panel dimensions: 116.80 x 168.60 mm.
Material: TG135
Solder Mask: Red
Silkscreen Color: White
Layers: 2
Finish: Lead-Free HASL
Thickness: 1.6mm
Outer Copper Weight: 1oz
Minimum track width: 0.20mm (8.00mil)
Minimum via drill: 0.30mm (11.81mil)

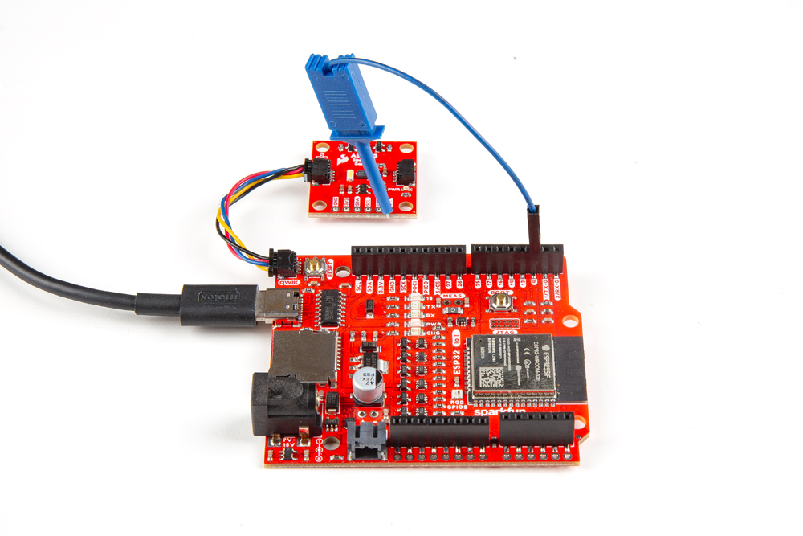
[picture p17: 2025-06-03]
docs/assets/img/AS7343_Interrupt_Assembly.jpg

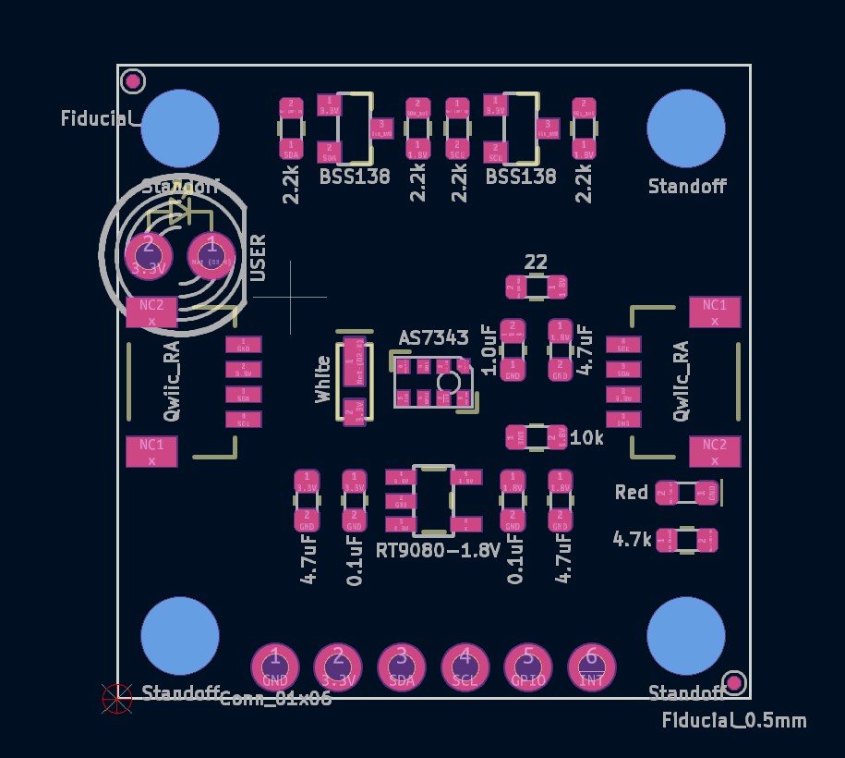
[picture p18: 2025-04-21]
Hardware/SparkFun_AS7343_Assembly_Sheet_v01.jpg

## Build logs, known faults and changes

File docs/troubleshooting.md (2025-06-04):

## Power Consumption Tips

The AS7343 boasts some impressively low power consumption numbers but the breakout board includes a few extra components that increase the total draw of the breakout. In our testing, the red Power LED is the biggest culprit and disabling it reduces total current consumption by roughly 300&micro;A. For example, opening the LED jumper to disable the LED drops current while idle from ~320&micro;A down to ~3&micro;A. 

Also, the on-board white LED defaults to draw 4mA from the AS7343's LED Drive pin while active so we recommend turning it on only when needed for spectral sensing. This is the *lowest* setting for the LED drive pin and can be adjusted to up to 12mA in both the Arduino library and Python package. Refer to the AS7343 [datasheet](./assets/component_documentation/AS7343_DS001046_6-00.pdf) for more information on driving an external LED.

## General Troubleshooting

!!! info
    <p><span class="glyphicon glyphicon-question-sign" aria-hidden="true"></span> <strong>Not working as expected and need help? </strong></p>
    <p>If you need technical assistance and more information on a product that is not working as you expected, we recommend heading on over to the <a href="https://www.sparkfun.com/technical_assistance">SparkFun Technical Assistance</a> page for some initial troubleshooting.</p>
    <center>
    [SparkFun Technical Assistance Page](https://www.sparkfun.com/technical_assistance){ .md-button .md-button--primary }
    </center>
    <p>If you can't find what you need there, you'll need a <a href="https://forum.sparkfun.com/ucp.php?mode=register">Forum Account</a> to search product forums and post questions.<p>

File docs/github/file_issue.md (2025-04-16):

# Did we make a mistake?

Spot something wrong? Please let us know. 

## Discrepancies in the Documentation

All of our documentation can be modified by you! Please help us make it better.

* The documentation files for these pages are contained in the [`docs` folder](https://github.com/sparkfun/SparkFun_Spectral_Sensor_Breakout_AS7343_Qwiic/tree/main/docs) of the [Spectral Sensor Breakout - AS7343 (Qwiic) repository](https://github.com/sparkfun/SparkFun_Spectral_Sensor_Breakout_AS7343_Qwiic).

### 🔍 Spot something wrong?

If a section of the documentation is incorrect, please [open an issue](https://github.com/sparkfun/SparkFun_Spectral_Sensor_Breakout_AS7343_Qwiic/issues) and let us know.

### Do you have a suggested correction?

1. With a GitHub account, [fork this repository](https://github.com/sparkfun/SparkFun_Spectral_Sensor_Breakout_AS7343_Qwiic/fork).
2. Add your correction(s) or improvement(s) to the markdown file(s)
3. File a pull request with your changes, and enjoy making the ~~words~~ ~~worlds~~ world a better place.
	* Once received, the documentation specialist will automatically be notified.
	* We will review your suggested improvement(s) to make sure they are correct and fit within our documentation standards.

## Problems in the Hardware Design

All of our designs are open-source! Please help us make it better.

* Our board design files are contained in the [`Hardware` folder](https://github.com/sparkfun/SparkFun_Spectral_Sensor_Breakout_AS7343_Qwiic/tree/main/Hardware) of the [Spectral Sensor Breakout - AS7343 (Qwiic) repository](https://github.com/sparkfun/SparkFun_Spectral_Sensor_Breakout_AS7343_Qwiic).

### Does something not make sense? 🤔

If part of the design is confusing, please [open an issue](https://github.com/sparkfun/SparkFun_Spectral_Sensor_Breakout_AS7343_Qwiic/issues) and let us know.

### Did we forget to include an important function of the board? 🤦

If part of the board's functionality is missing, please [open an issue](https://github.com/sparkfun/SparkFun_Spectral_Sensor_Breakout_AS7343_Qwiic/issues) and file a feature request.

!!! tip "Design Considerations"
	Please keep in mind that we may intentionally exclude certain functions of the board to meet our product design requirements.
	
	* *For example, our Qwiic Micro boards are intended to fit on a small board layout and only use I<sup>2</sup>C communication; therefore, we may not have the SPI and interrupt pins available for users.*

### Do you wish to contribute directly to improving the board design?

1. With a GitHub account, [fork this repository](https://github.com/sparkfun/SparkFun_Spectral_Sensor_Breakout_AS7343_Qwiic/fork).
2. Add your design augmentation(s)
3. File a pull request with your changes, and enjoy making the ~~words~~ ~~worlds~~ world a better place.
	1. Once received, the engineer in charge of the original design will automatically be notified.
	2. We will review your suggested improvement(s) to verify that they are within our board design standards and meet our product design requirements.
	3. If approved, we will flag these changes for our next board revision. Congrats! 🍻

		!!! info
			Even if your suggestion is accepted, these changes may not be immediately available for purchase. We may have to cycle through our current product inventory first.

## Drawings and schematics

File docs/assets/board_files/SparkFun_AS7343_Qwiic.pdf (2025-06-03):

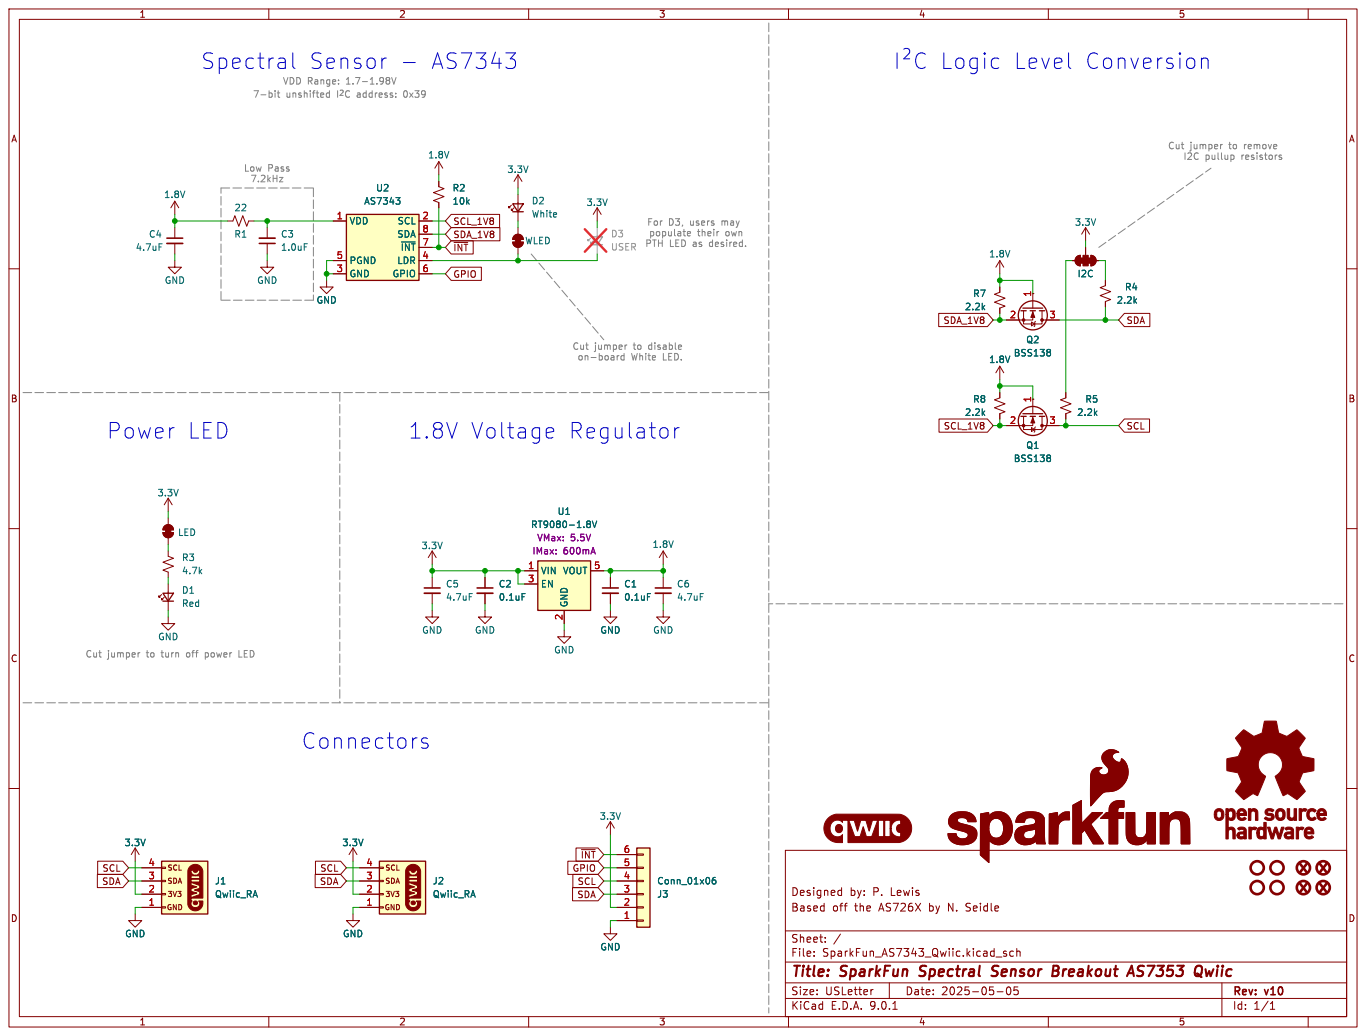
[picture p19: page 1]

Cut jumper to turn off power LED Spectral Sensor - AS7343

Id: 1/1 Title: SparkFun Spectral Sensor Breakout AS7353 Qwiic

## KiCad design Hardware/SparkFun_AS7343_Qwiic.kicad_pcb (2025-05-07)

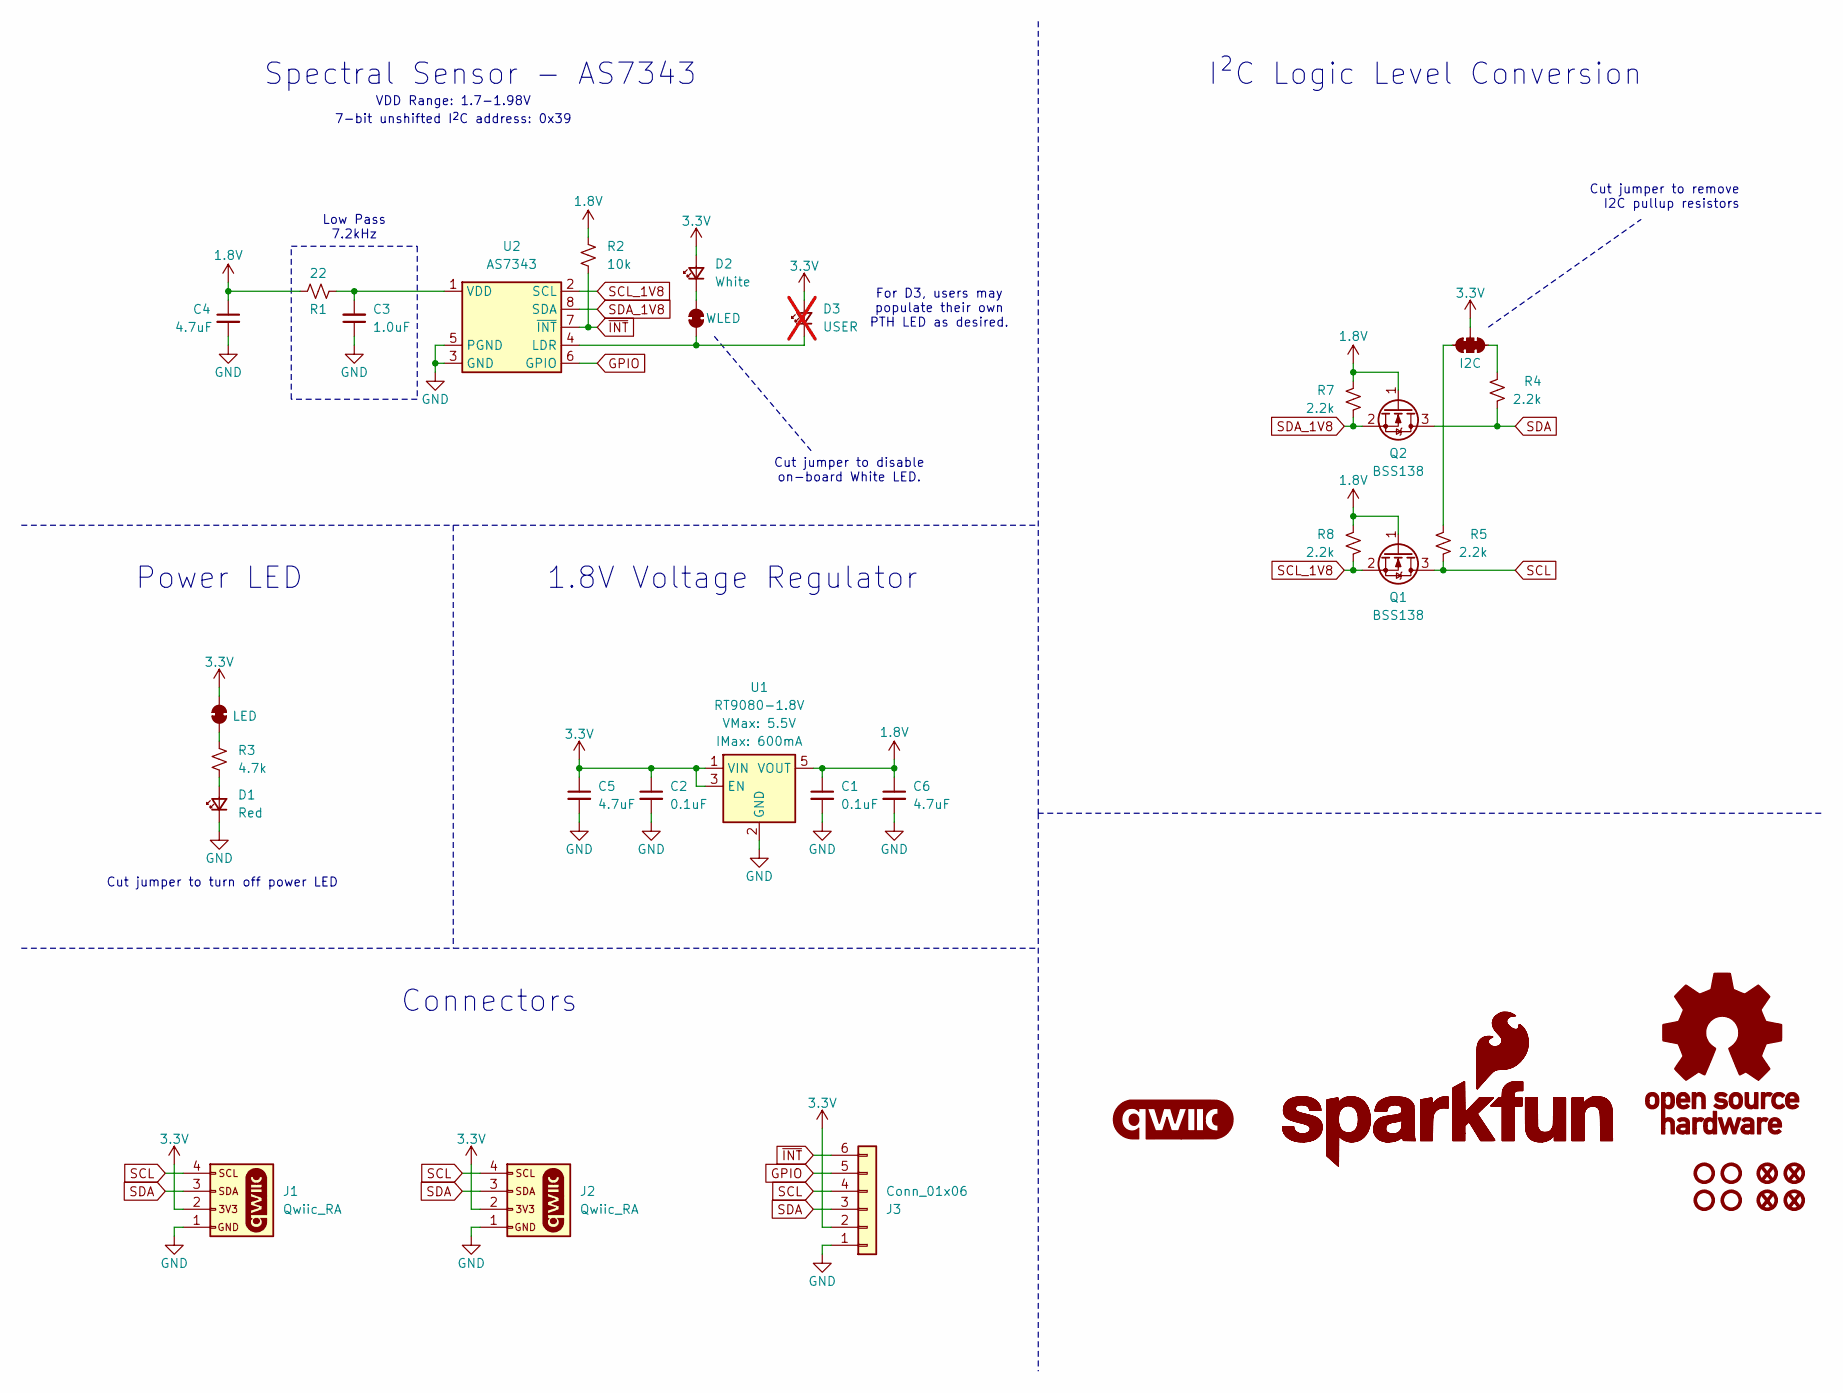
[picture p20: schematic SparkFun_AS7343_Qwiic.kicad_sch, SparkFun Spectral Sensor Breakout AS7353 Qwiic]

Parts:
C1, C2: 0.1uF; C_0603_1608Metric; Voltage 25V; Tolerance 20%
C3: 1.0uF; C_0603_1608Metric; Voltage 16V; Tolerance 10%
C4, C5, C6: 4.7uF; C_0603_1608Metric; Voltage 35V; Tolerance 20%
D1: Red; LED_0603_1608Metric_Red
D2: White; LUXEON_3014_SMD_LED
D3: USER; LED_5mm_PTH_Red_NoSilk; not fitted
FID1, FID2, FID3, FID4: Fiducial_0.5mm; Fiducial_0.5mm_Mask1mm
G1: qwiic_Logo
G2: SparkFun_Logo; SparkFun_Logo_8mm
G3: SparkFun_Logo
G4: OSHW_Logo; Creative_Commons_License
J1, J2: Qwiic_RA; JST_SMD_1.0mm-4_Black
J3: Conn_01x06; 1x06
JP1: LED; Jumper_2_NC_Trace
JP2: I2C; Jumper_3_NC-2_Trace
JP3: WLED; Jumper_2_NC_Trace
Q1, Q2: BSS138; SOT23-3
R1: 22; R_0603_1608Metric
R2: 10k; R_0603_1608Metric
R3: 4.7k; R_0603_1608Metric
R4, R5, R7, R8: 2.2k; R_0603_1608Metric
ST1, ST2, ST3, ST4: Standoff
U1: RT9080-1.8V; SOT23-5
U2: AS7343; AMS_OLGA-8_2x3.1mm_P0.8mm

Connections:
1.8V: C1.1, C4.1, C6.1, Q1.1 (G), Q2.1 (G), R1.1, R2.2, R7.1, R8.1, U1.5 (VOUT)
3.3V: C2.1, C5.1, D2.2 (A), D3.2 (A), J1.2, J2.2, J3.2, JP1.2 (B), JP2.2 (B), U1.1 (VIN), U1.3 (EN)
GND: C1.2, C2.2, C3.1, C4.2, C5.2, C6.2, D1.1 (K), J1.1, J2.1, J3.1, U1.2 (GND), U2.3 (GND), U2.5 (PGND)
GPIO: J3.5, U2.6 (GPIO)
unnamed: D1.2 (A), R3.1
unnamed: D2.1 (K), JP3.1 (A)
unnamed: D3.1 (K), JP3.2 (B), U2.4 (LDR)
unnamed: JP1.1 (A), R3.2
unnamed: JP2.1 (A), R5.1
unnamed: JP2.3 (C), R4.2
unnamed: C3.2, R1.2, U2.1 (VDD)
SCL: J1.4, J2.4, J3.4, Q1.3 (D), R5.2
SCL_1V8: Q1.2 (S), R8.2, U2.2 (SCL)
SDA: J1.3, J2.3, J3.3, Q2.3 (D), R4.1
SDA_1V8: Q2.2 (S), R7.2, U2.8 (SDA)
~INT: J3.6, R2.1, U2.7 (~INT)

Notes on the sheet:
Low Pass 7.2kHz
For D3, users may populate their own PTH LED as desired.
Cut jumper to remove I2C pullup resistors
1.8V Voltage Regulator
7-bit unshifted I^{2}C address: 0x39
I²C Logic Level Conversion
Cut jumper to turn off power LED
Cut jumper to disable on-board White LED.
Power LED
VDD Range: 1.7-1.98V
Connectors
Spectral Sensor - AS7343

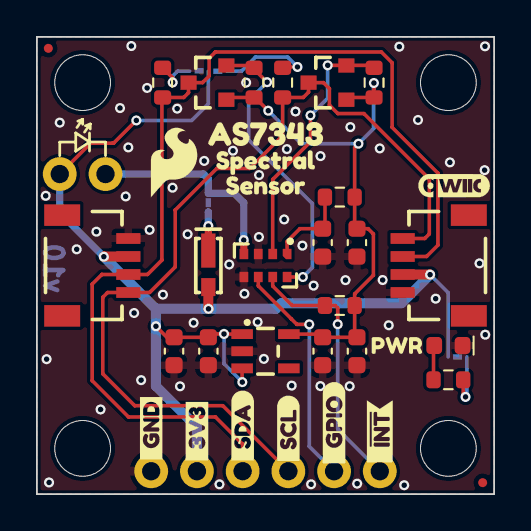
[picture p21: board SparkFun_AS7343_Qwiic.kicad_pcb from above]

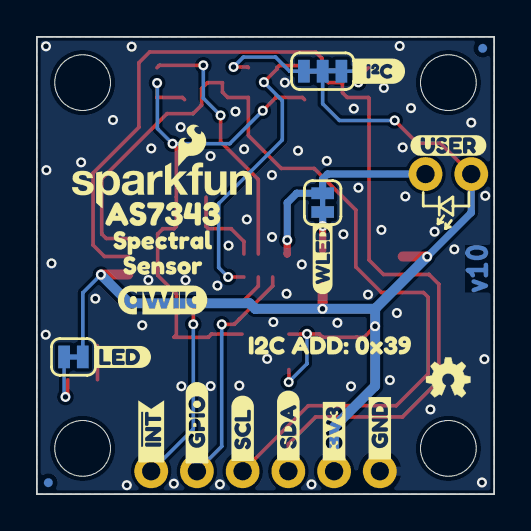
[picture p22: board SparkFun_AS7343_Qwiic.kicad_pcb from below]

Board: 2 copper layers, 25.4 x 25.4 mm, 60 parts (20 on the bottom side), 16 nets.

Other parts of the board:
Ref**: Val**; OSHW_Logo_2.5mm
kibuzzard-65A8A8B4: G***; kibuzzard-65A8A8B4
kibuzzard-67BF7CFE: G***; kibuzzard-67BF7CFE
kibuzzard-67BF7F2F: G***; kibuzzard-67BF7F2F
kibuzzard-67BF7F13: G***; kibuzzard-67BF7F13
kibuzzard-67ED66D1, kibuzzard-67ED66D1#2: G***; kibuzzard-67ED66D1
kibuzzard-67ED66F3, kibuzzard-67ED66F3#2: G***; kibuzzard-67ED66F3
kibuzzard-67ED66FD, kibuzzard-67ED66FD#2: G***; kibuzzard-67ED66FD
kibuzzard-67ED691F, kibuzzard-67ED691F#2: G***; kibuzzard-67ED691F
kibuzzard-67ED694E, kibuzzard-67ED694E#2: G***; kibuzzard-67ED694E
kibuzzard-67ED714F: G***; kibuzzard-67ED714F
kibuzzard-67ED716A: G***; kibuzzard-67ED716A
kibuzzard-67ED6905: G***; kibuzzard-67ED6905
kibuzzard-67ED7158: G***; kibuzzard-67ED7158
kibuzzard-67ED7177: G***; kibuzzard-67ED7177
kibuzzard-67ED7915: G***; kibuzzard-67ED7915
kibuzzard-67F027E1: G***; kibuzzard-67F027E1
kibuzzard-67F954F3: G***; kibuzzard-67F954F3
kibuzzard-67F8112D: G***; kibuzzard-67F8112D
kibuzzard-67F81140: G***; kibuzzard-67F81140

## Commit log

2025-04-02 layout pretty much there
    [SparkFun_AS7343_Qwiic.kicad_pcb, SparkFun_AS7343_Qwiic.kicad_sch]
2025-04-03 3d models
    -created 3d models for AS7343 and Luxeon 3014
    -add datasheet link to AS7343 symbol
    [AS7343_OLGA8.FCStd, AS7343_OLGA8.step, LUXEON_3014.FCStd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]
2025-04-03 remove extra directory - resave in kicad 9.0
    [AS7343_OLGA8.FCStd, AS7343_OLGA8.step, LUXEON_3014.FCStd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]
2025-04-04 PROD_IDs
    -prod IDs for IC and white LED
    [SparkFun_AS7343_Qwiic.kicad_pcb, SparkFun_AS7343_Qwiic.kicad_sch]
2025-04-04 low pass filter components moved and re-routed
    -rotated parts so that C3 and C4 have direct GND return paths to IC GND pads (and Vreg GND pads)
    [SparkFun_AS7343_Qwiic.kicad_pcb]
2025-04-04 PTH pad LED silk update
    -Added arrows to silk graphics, to clearly show it's an LED (rather than just a diode)
    [SparkFun_AS7343_Qwiic.kicad_pcb]
2025-04-04 I2C address in sch and bottom silk
    [SparkFun_AS7343_Qwiic.kicad_pcb, SparkFun_AS7343_Qwiic.kicad_sch]
2025-04-04 checklist run eng
    -sch tightening
    -vcc range added to sch
    -removed PROD_ID from DNP LED
    -add 1.8V testpoint
    -increased copper to dimension clearance from 3 mils to 8 mils (avoiding sanding damage)
    -nudged qwiic connectors inward from the edge by 5mils (avoiding sanding damage)
    -updated pin one marker on IC from triangle to dot
    [SparkFun_AS7343_Qwiic.kicad_pcb, SparkFun_AS7343_Qwiic.kicad_sch]
2025-04-04 move measures to correct layer
    [SparkFun_AS7343_Qwiic.kicad_pcb]
2025-04-08 catches in review
    -corrected GPIO and INT silk labels
    -rerouted traces near power LED and R3
    -removed a ground nubbin on pad of C4
    [SparkFun_AS7343_Qwiic.kicad_pcb]
2025-04-09 more review catches
    -Checked the properties box for DNP on D3, also exclude from BOM.
    -sch cleanup
    -removed isolation jumper for 1v8 i2c pullups
    [SparkFun_AS7343_Qwiic.kicad_pcb, SparkFun_AS7343_Qwiic.kicad_sch]
2025-04-09 reduced paste on IC pads by 10%
    [SparkFun_AS7343_Qwiic.kicad_pcb]
2025-04-10 more review notes
    -changed 1V8 to 1.8V to match style of 3.3V
    -corrected schematic note for low pass filter. Is kHz, was KHz
    -removed one of the QWIIC logos
    -Moved OSHW to bottom silk
    -aligned PWR LED silk label exactly with Y val of LED.
    -changed sch note about i2c address to be "7-bit unshifted I2C address: 0x39"
    [SparkFun_AS7343_Qwiic.kicad_pcb, SparkFun_AS7343_Qwiic.kicad_sch]
2025-04-10 everything moved to 12.5 mil grid
    -moved all parts to 12.5 mil grid and re-routed as necessary
    [SparkFun_AS7343_Qwiic.kicad_pcb]
2025-04-11 eng checklist for protos v01
    -solder mask changed to black for protos
    -DRC exclusions
    [SparkFun_AS7343_Qwiic.kicad_pcb]
2025-04-11 added USER LED label to bottom silk
    -changed value ot D3 to "USER"
    -added silk label to bottom for USER LED
    [SparkFun_AS7343_Qwiic.kicad_pcb, SparkFun_AS7343_Qwiic.kicad_sch]
2025-04-11 prototype gerbers v01
    [SparkFun_AS7343_Qwiic.GBL, SparkFun_AS7343_Qwiic.GBO, SparkFun_AS7343_Qwiic.GBP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]
2025-04-14 library work
    -updated PTH USER LED (DNP) to have fab outline and 3d model link for reference only
    [SparkFun_AS7343_Qwiic.kicad_pcb, SparkFun_AS7343_Qwiic.kicad_sch]
2025-04-21 Assembly sheet v01
    -repositioned values for better assembly sheet
    -screenshot of assembly sheet for v01
    [SparkFun_AS7343_Qwiic.kicad_pcb]
2025-04-22 fixed logic level converters
    -body diodes in LLC transistors were allowing high side voltage into low side. (This was incorrect in v01).
    -fixed LLC circuit to have low/high voltages on the correct sides
    -rerouted
    -bumped version to v02
    [SparkFun_AS7343_Qwiic.kicad_pcb, SparkFun_AS7343_Qwiic.kicad_sch]
2025-05-05 bumped version to v10 in sch and pcb
    [SparkFun_AS7343_Qwiic.kicad_pcb, SparkFun_AS7343_Qwiic.kicad_sch]
2025-05-07 eng checklist run for v10
    -updated soldermask color to red
    -library update on the DNP 5mm pth LED (linking due to new naming)
    -library update on qwiic connector - looks like just an update on the courtyard
    [SparkFun_AS7343_Qwiic.kicad_pcb, SparkFun_AS7343_Qwiic.kicad_sch]
2025-05-07 production panel and gerbers v10
    [SparkFun_AS7343_Qwiic_panelized.GBL, SparkFun_AS7343_Qwiic_panelized.GBO, SparkFun_AS7343_Qwiic_panelized.GBP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]
2025-05-19 Docs update
    Update to Arduino section to match latest library release & Quick Start guide update to finalize Arduino portion of the guide.
2025-05-20 Minor docs update
    Adding screenshots for arduino examples & minor updates to software setup & assembly sections.
2025-06-03 Docs photo & initial review update
    Adding photos and board files to assets. General updates to prep for final review.
2025-06-06 White Luxeon LED datasheet and power graph

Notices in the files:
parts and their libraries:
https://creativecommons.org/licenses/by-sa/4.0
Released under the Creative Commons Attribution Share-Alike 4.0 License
